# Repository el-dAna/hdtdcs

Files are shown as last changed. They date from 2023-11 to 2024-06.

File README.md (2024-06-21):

# HIGH-DEFINITION TRANSCRANIAL DIRECT CURRENT STIMULATION (hdtdcs) DEVICE DESIGN AND IMPLEMENTATION. (TÜBİTAK)
Circiut design showing major componets and functionality.


High Difinition Transcranial Direct Current Stimulation basically is the idea of passing direct current (usually 2mA) through electrodes through the skull to enhance(polarise) or suppress(hyperpolarise) brain activity.
This project was aimed at designing and constructing a functional hd-TDCS device for the potential treatment of derug resistant epilepsy.
## What is TDCS

## What is hd-TDCS

## Advantages of hd-TDCS

## Circuit description and function

#### Falstad simulation
The insert below is a screen shot of the main function of the circuit on falstad. It shows the major components: 9V DC voltage source, 12bit DAC and transistors. We implemeented a 6 electrode hdTDCS (1 anode+ and 5 cathodes-) for the potential application in the treatment of drug resistant focal epilepsy. The point at which the 6 wires meet is the practical position of the head. As shown, current through the cathodes is 2mA and total current through anode is 10mA approx. 


#### Circuit Schematic and EASY EDA 3D PCB design.


#### Lab implementation
The image below is the soldered version in the lab. We verified the output volage from the DAC to the bases of the transistors. Practically the input DC voltage should be kept at 9V so we included a 9V regulator and supplied >9V.


#### Final prototype case
The case is to contain the circuit board, microcontroller and voltage source. Side ports included for easy plugging of microcontroller to computer for easy debugging. 
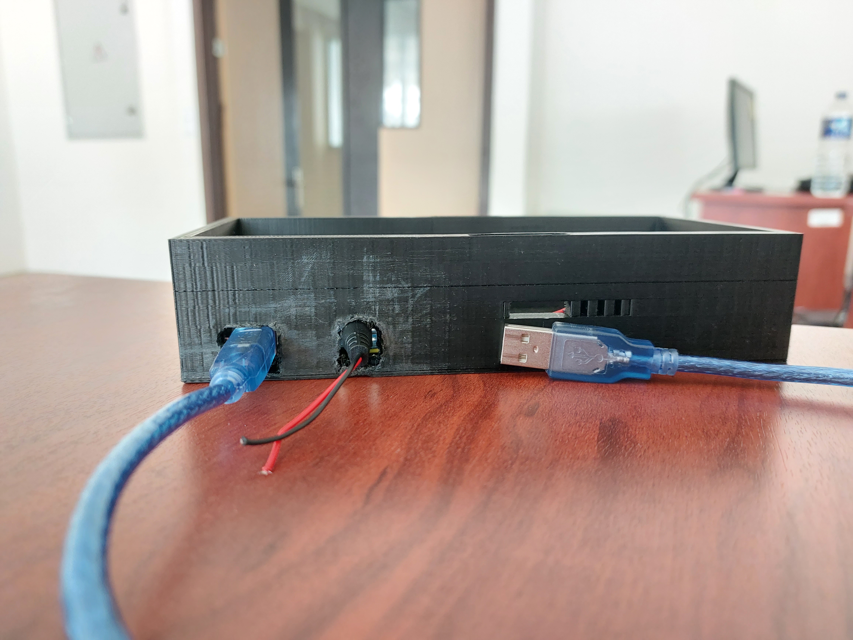
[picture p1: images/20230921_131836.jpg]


## AutoCad Designs
#### The electrode and gel holder from conception to CAD design to 3D printing.


#### The head strio and electrode holder CAD designs.


## [Simibs](https://simnibs.github.io/simnibs/build/html/index.html) Current Distribution Simulation MRI scans.
#### Simnibs is an open surce software for non-invasive brain stimulation(TMS-Transcranila Magnetic Stimulation and TDCS-Transcranial Direct Current Stimulation) simulation.


## Contributors
Marya Alhajmohammadothman
Benjamin Sogodam Atadana [X](https://twitter.com/hey_eldana)

## Supervisors
Prof. Dr. Hilal Göktaş [X](https://twitter.com/Goktashil)
Prof. Dr. Mehmet Yüksekkaya

## Funding
2209-A Üniversite Öğrencileri Araştırma
Projeleri Destekleme Programı 2022 Yılı 2.
[X](https://twitter.com/Tubitak)

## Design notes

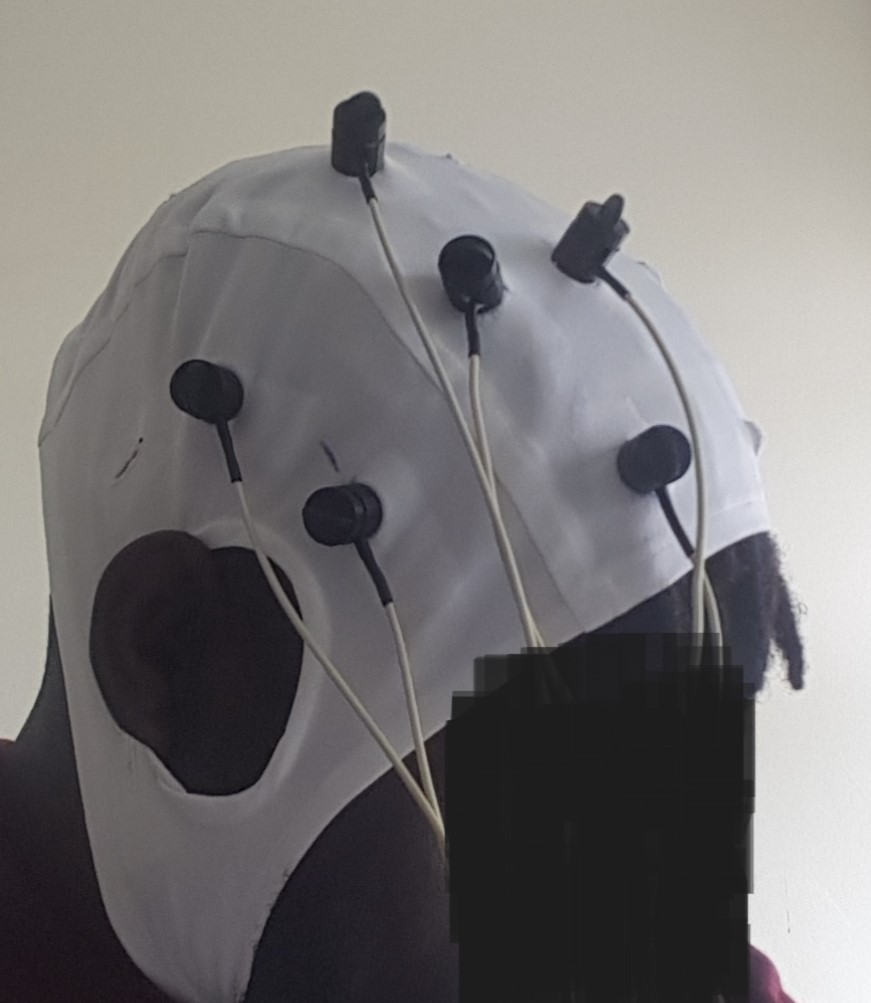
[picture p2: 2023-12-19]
images/eeg_cap_with_electrodes.jpg

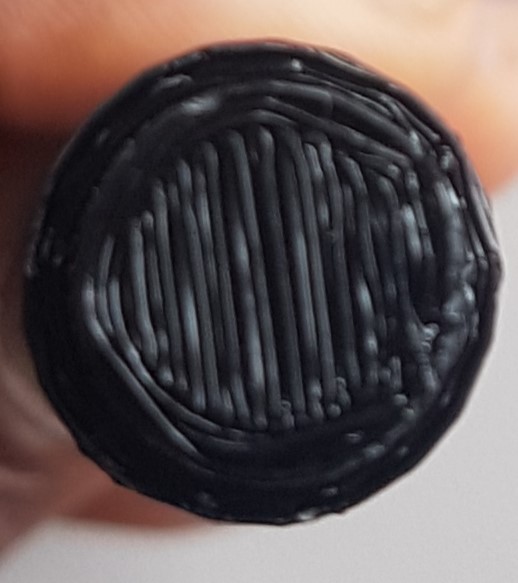
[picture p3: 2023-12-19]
images/electrode_cap_bottom.jpg

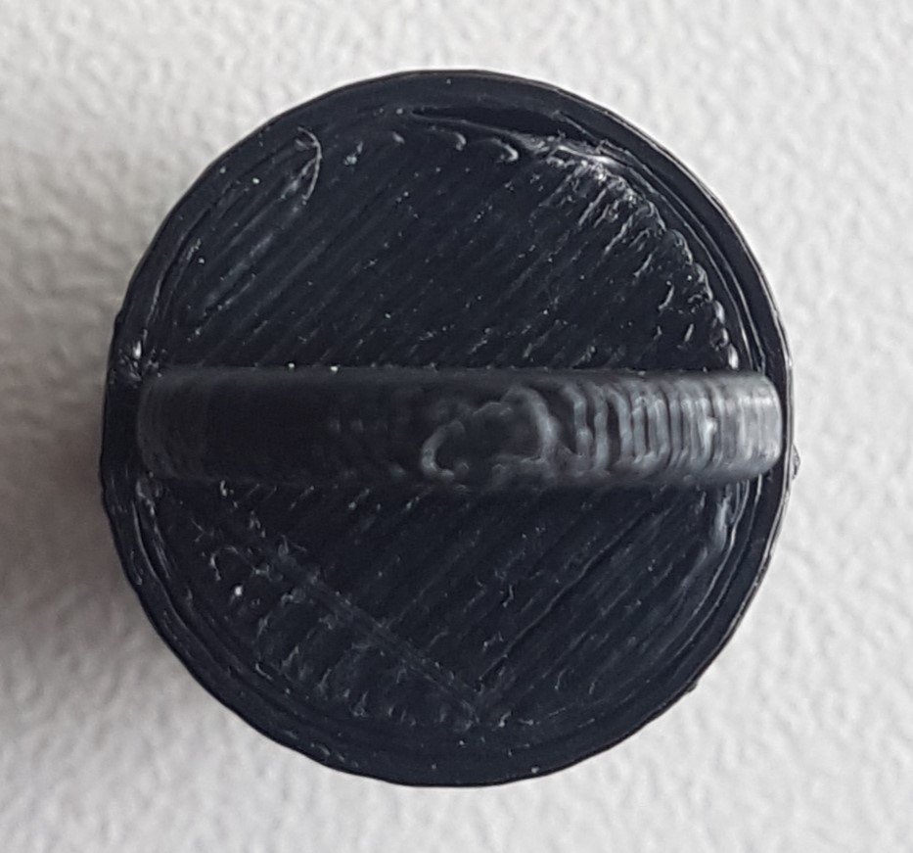
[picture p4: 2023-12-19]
images/electrode_cap_top.jpg

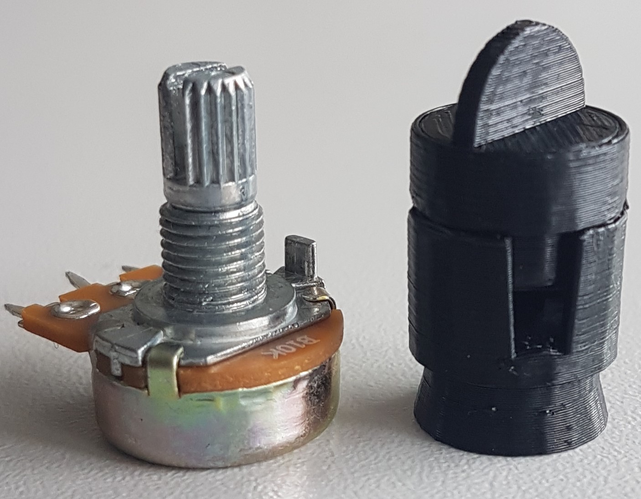
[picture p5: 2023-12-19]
images/electrode_holder_potentiometer.jpg

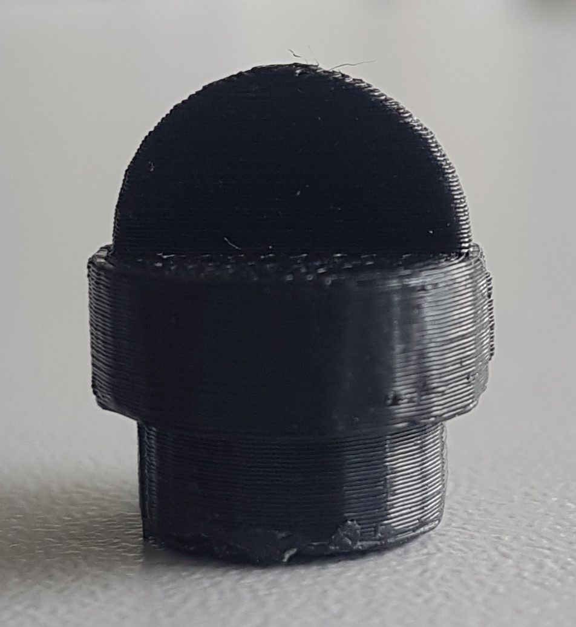
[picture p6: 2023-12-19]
images/electrode_cap_front.jpg

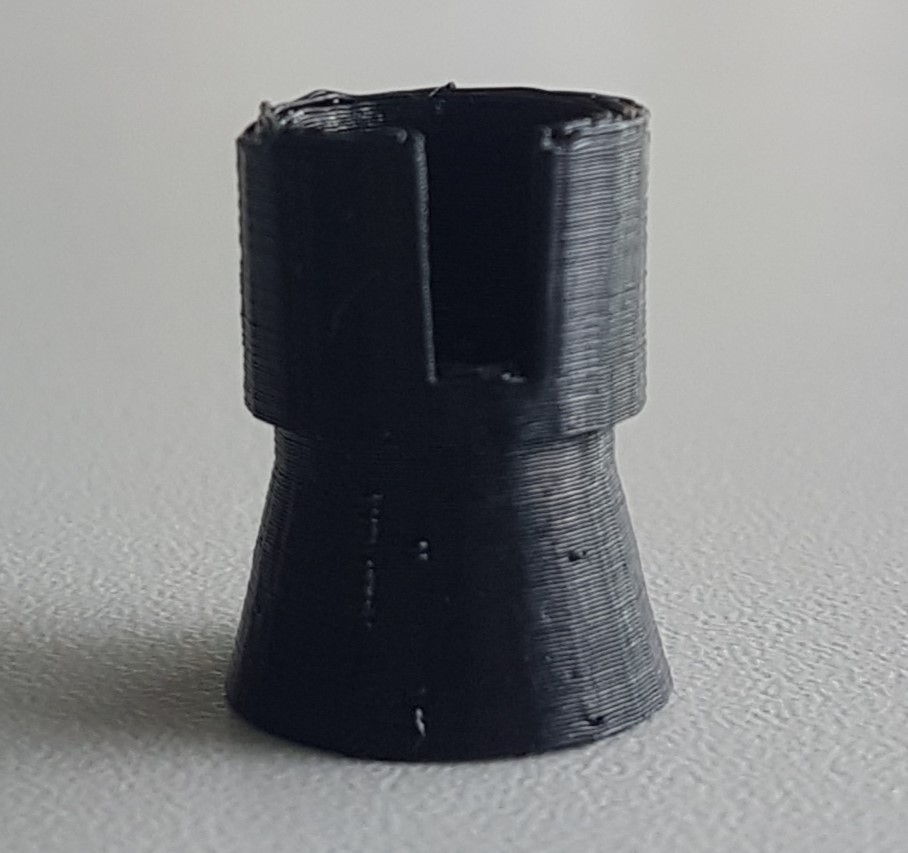
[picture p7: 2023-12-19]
images/electrode_holder_iso.jpg

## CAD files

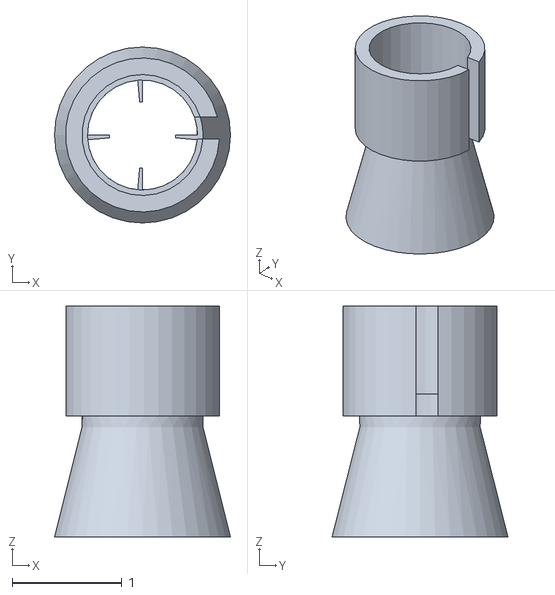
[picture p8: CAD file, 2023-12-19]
CADdesings/AgCl_holder.stl
1.60 x 1.60 x 2.10

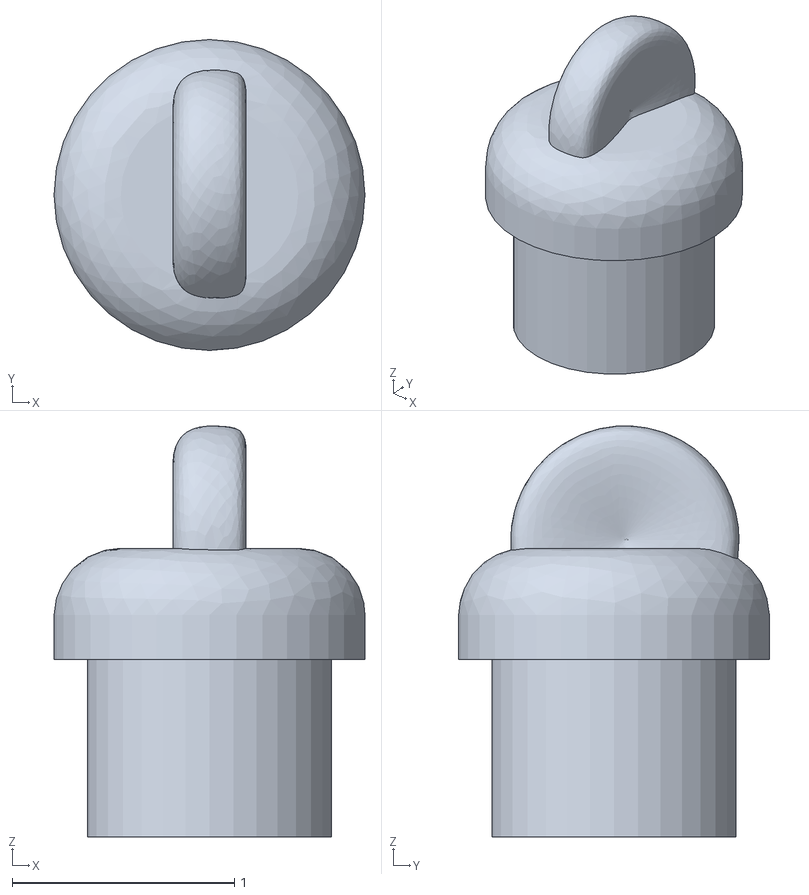
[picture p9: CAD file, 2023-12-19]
CADdesings/Electrode_Cap.stl
1.40 x 1.40 x 1.85

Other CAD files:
CADdesings/Tuseb_final_headstrip.dwg
CADdesings/Tuseb_electrode_holder.dwg
CADdesings/Tuseb_electrode.dwg
CADdesings/Tubitak_models_recover.dwg
CADdesings/Drawing1.dwg
CADdesings/TubitakCasePrototype.dwg
CADdesings/Tubitak_models.dwg
CADdesings/AgCl_holder.dwg
CADdesings/Electrode_Cap.dwg

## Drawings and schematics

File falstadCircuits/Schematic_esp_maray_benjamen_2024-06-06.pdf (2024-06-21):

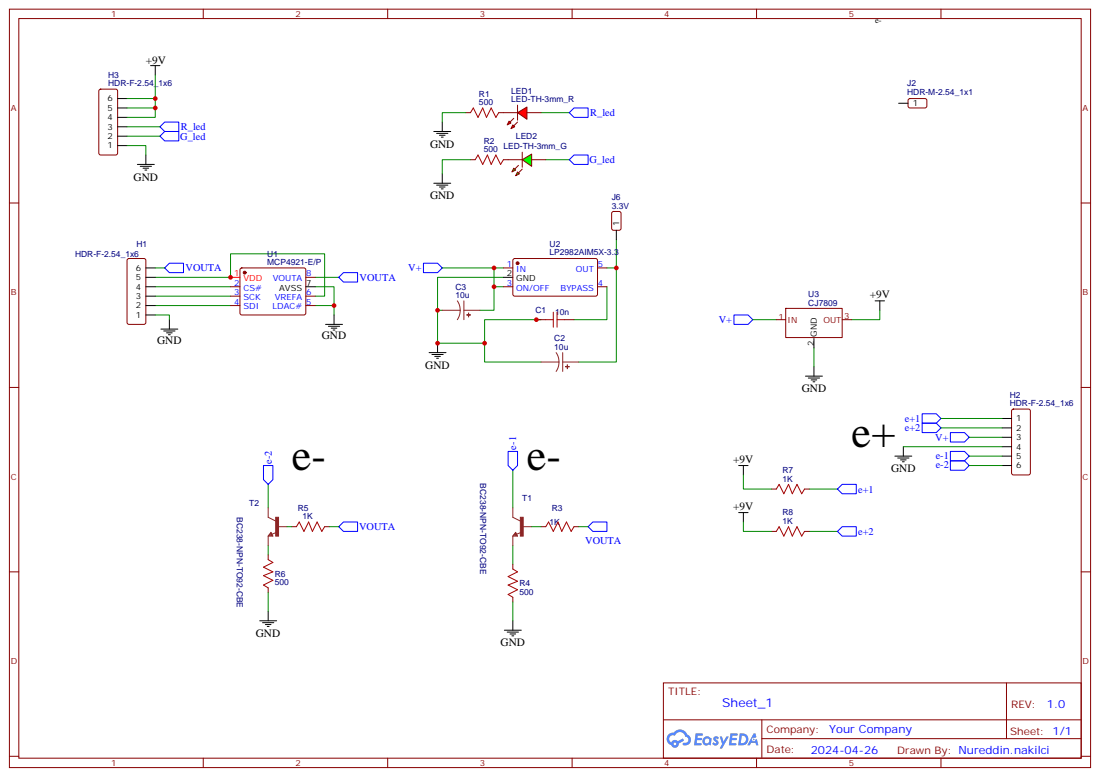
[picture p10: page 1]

Drawn By: Nureddin.nakilci

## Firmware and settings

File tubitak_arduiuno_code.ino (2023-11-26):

#include <LiquidCrystal.h>
#include "MCP_DAC.h" //reference the library files
MCP4921 hdTDCs_DAC(5, 2); //third and second yellow wires from the red 5V input to DAC from Arduiuno     //create DAC object https://cyberblogspot.com/how-to-use-mcp4921-dac-with-arduino/
// Assuming we are using D9 pin for MOSI and D8 pin for SCLK, we create the MCP_DAC object in this manner:
int DAC_output_pin = 3; //yellow wire close to red 5V input to DAC from Arduiuno 

//UNIVERSAL VARIABLES FOR LCD DISPLAY
int numCols = 16;
int numRows = 2;
int scrollSpeed_beforeStimulation = 1000;
int scrollSpeed_forStimulation = 1000;

//UNIVERSAL VARIABLES FOR DAC
const int electrode = A0; //9V red cable voltage from voltage regulator to arduiuno
const int five_volt_probe = A2; //5V orange cable from arduiuno to DAC Vin
const int DAC_output_voltage_probe = A1; // blue cable to measure output voltage of DAC

// Due to circuit connections, the usual output range of DAC(0-5V) changed to (0-3.6)V. The old integer input to DAC was (0-4095) from Datasheet
// The DAC object now takes integer values from (0-3000) to output (0-3.6)V.
float  Set_DAC_Vout = 1000; //1480; // Tune DAC Vout here to ouput the required voltage for required current(10mA total) bu inputing values in range (0-3000)

float expected_DAC_Vout = (183/152000)*Set_DAC_Vout;
float low_expected_DAC_Vout = ((183/152000)*Set_DAC_Vout)-0.1;
float high_expected_DAC_Vout = ((183/152000)*Set_DAC_Vout)+0.1;

// CONNECTION OF LCD TO PINS
// LCD Variables. Check out this blog post https://toptechboy.com/arduino-tutorial-48-connecting-and-using-an-lcd-display/
int rs=7;
int en=8;
int d4=9;
int d5=6;
int d6=11;
int d7=12;
LiquidCrystal lcd(rs,en,d4,d5,d6,d7); 

// VARIABLE TO CHECK FOR THE VOLTAGE AT THREE POINTS.
bool all_passed;
int number_of_warns = 1;

// MESSAGES TO DISPLAY ON LCD
String Welcome = "tDCS stimulation starts in...";
String stimulationMessage = "Active hdTDCs....";
String afterStimulation = "Stimulation Done!";



void setup(){

  //Initial count-down to the start of stimulation
  Serial.begin(9600);
  hdTDCs_DAC.begin(DAC_output_pin);
  lcd.begin(numCols, numRows);
  OnStart(Welcome, scrollSpeed_beforeStimulation, 0.1);
  lcd.clear();
  delay(2000);



  // Checking for voltages. Precisely the 5v input to DAC(Blue) and Vout(Orange) from DAC to electrodes
  
  // run_checks_again: // a checkpoint to return to if any of the checks fail. if any check fail then 10mA current will not be output!
  // all_passed = Run_Checks(low_expected_DAC_Vout, high_expected_DAC_Vout);
  // if (!all_passed){
  //   number_of_warns++;
  //   goto run_checks_again;
  // };
}


void loop() {  

  // Start of stimulation if all tests passed, thus we have the correct voltages at the check points
  Stimulation(true, Set_DAC_Vout); //
  OnStart(stimulationMessage, scrollSpeed_forStimulation, 0.2); //to display message during stimulation
  lcd.clear();
  lcd.setCursor(0, 0);


  // hdTDCs_DAC.analogWrite(0);
  Stimulation(false, Set_DAC_Vout);
  lcd.print(afterStimulation);
  delay(2000);
  exit(0);
}




void Stimulation(bool active, float set_DAC_Vout){
  if (active){
    hdTDCs_DAC.analogWrite(set_DAC_Vout);
  }else{
    hdTDCs_DAC.analogWrite(0);
  }
}





bool assertWithErrorMessage(bool condition, String possible_error, float measured_voltage) {
  bool passed_check = true;
  if (!condition) {
    //If monitor available
    Serial.print("WARNING ");
    Serial.println(number_of_warns);
    Serial.print(measured_voltage);
    Serial.println("Volts");
    Serial.println(possible_error);
    delay(3000);
    
    //If only LCD available
    lcd.clear();
    lcd.setCursor(0, 0);
    lcd.print("WARN");
    lcd.setCursor(5, 0);
    lcd.print(number_of_warns);
    lcd.setCursor(9, 0);
    lcd.print(measured_voltage);
    lcd.setCursor(13, 0);
    lcd.print("V");
    lcd.setCursor(0, 1);
    lcd.print(possible_error);
    
    passed_check = false;
    //exit(0);
  }
  return passed_check;
}



float get_voltage(int AnaloguePin, bool SerialMonitor) {
  int analogValue = analogRead(AnaloguePin);
  // Convert the analog value to a voltage
  float voltage = analogValue * (5.0 / 1023.0);

  if (SerialMonitor) {
    // Print the voltage to the serial port
    Serial.print("Voltage: ");
    Serial.println(voltage);
    // Wait for 1 second
    delay(1000);
  }
  return voltage;
}




bool Run_Checks(float lower_limit_DAC_Voltage_Out, float upper_limit_DAC_Voltage_Out ){

  bool checks_list[3]; // initialised list to store outcome of checks for checks_list[0],9V, checks_list[1],5V to DAC and checks_list[2],Vout from DAC

  // 9V is too big to connect to Analogue pin and have another external power source. This breaks down the arduiuno
  // //Checks 9V from voltage regulator to arduiuno
  // float voltage_at_electrodes = get_voltage(electrode, false);
  // bool condition_A0 = voltage_at_electrodes >= 9; //this is fixed, Vout of 9V regulator
  // bool condition_A0_result = assertWithErrorMessage(condition_A0, "Wrong eltrd. V!", voltage_at_electrodes);
  
  //Checks 5V from arduiuno to DAC
  float Five_Volt_to_DAC = get_voltage(five_volt_probe, false);
  bool condition_A2 = Five_Volt_to_DAC >= 4.7; // this is fixed, close to 5V from arduiuno
  bool condition_A2_result = assertWithErrorMessage(condition_A2, "Wrong DAC V_in!", Five_Volt_to_DAC);

  //checks the Vout of DAC to electrodes
  float DAC_Vout = get_voltage(DAC_output_voltage_probe, false);
  bool condition_A1 = (DAC_Vout >= lower_limit_DAC_Voltage_Out) & (DAC_Vout <= upper_limit_DAC_Voltage_Out); //tune DAC to output 10mA and set that voltage 
  bool condition_A1_result = assertWithErrorMessage(condition_A1, "Wrong DAC V_out!", DAC_Vout);

  //checks_list[0] = condition_A0_result;
  checks_list[1] = condition_A1_result;
  checks_list[2] = condition_A2_result;
  bool all_checks_passed = checks_list[1] & checks_list[2]; // & checks_list[0]; 

  return all_checks_passed;
}




void OnStart(String message, int scrollSpeed, float minutes) {
  int count = minutes*60;
  int mins = 0;
  float secs = 0;
  bool later_rounds = false;
  lcd.clear();

  while(count > 0) {
    for (int i = 0; i < message.length() - numCols + 1; i++) {
      //lcd.clear();
      if (count < 0){break;}
      lcd.setCursor(0, 0);
      lcd.print(message.substring(i, i + numCols));
      delay(scrollSpeed);

      if (later_rounds == true){
        mins = count/60;
        secs = count-(mins*60);
        lcd.setCursor(4, 1);
        lcd.print(mins);
        lcd.print(":");
        lcd.print(secs);
        count = count - 1;
      }
    }
    later_rounds = true;
    //delay(1000);
  }
}













// #include "MCP_DAC.h" //reference the library files
// #include <LiquidCrystal.h>
// MCP4921 myDAC;       //create DAC object

// int numCols = 16;
// int numRows = 2;
// int scrollSpeed = 500;
// int rs=7;
// int en=8;
// int d4=9;
// int d5=6;
// int d6=5;
// int d7=12;
// LiquidCrystal lcd(rs,en,d4,d5,d6,d7);


// void setup() {
//   lcd.begin(16, 2);
//   lcd.print("5-Min Countdown gtg bstt sthgs thtr tht ");
//   delay(2000); // Display the title for 2 seconds
//   lcd.clear();
//   countdown(2); // Start a 5-minute countdown
// }

// void loop() {
//   // Your main loop code here (if needed)
// }




// void countdown(int minutes) {
//   int count = minutes*60;
//   int mins = 0;
//   float secs = 0;

//   while ( count > 0) {
//       lcd.setCursor(0, 0);
//       lcd.print("Time Left: ");
//       count = count - 1;
//       mins = count/60;
//       secs = count-(mins*60);
//       lcd.setCursor(4, 1);
//       lcd.print(mins);
//       lcd.print(":");
//       lcd.print(secs);
//       delay(1000);
//     }
//   lcd.clear();
// }

// void ActiveStimulation(MCP4921 DAC, int stimulationTime) {
//   DAC.analogWrite(2048);
//   String activeStimulationMessage = "hdTDCS Stimulation";

//   countdown(activeStimulationMessage, stimulationTime);
// }

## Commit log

2023-12-19 added images, cad designs and falstad circuit for tubitak design
    [AgCl_holder.dwg, AgCl_holder.stl, Drawing1.dwg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]
2024-06-21 Add files via upload
    Uploaded files for Tuseb head strip desings for hd-tdcs
    [Tuseb_electrode.dwg, Tuseb_electrode_holder.dwg, Tuseb_final_headstrip.dwg]
2024-06-21 Uploaded the Gerber file for the Tuseb circuit
2024-06-21 schematic for the pcb design on easy eda
